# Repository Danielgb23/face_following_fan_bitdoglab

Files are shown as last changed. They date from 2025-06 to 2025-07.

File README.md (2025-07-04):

# Ventilador Seguidor de Rostos - BitDogLab

##  Descrição
Sistema inteligente de embarcados que move um ventilador para seguir rostos detectados por uma IA de visão computacional. 

[Link](https://youtu.be/tgpLVKnkNZ8) do vídeo de demonstração. 



### Proposta de projeto
Neste projeto nós propomos criar um sistema que controla a direção que uma ventoinha aponta baseado na posição da face do usuário em relação a uma câmera fixa. A câmera escolhida (ESP32) captura a imagem e envia para um notebook próximo. O notebook realiza uma análise da imagem recebida, identificando uma face ( se houver ) e as coordenadas dela em relação ao centro da câmera, depois envia essas coordenadas para o BitDogLab.
O BitDogLab, tendo a posição da face recebida, controla dois servos motores, um que controla o movimento vertical e outro o horizontal, e direciona a ventoinha para apontar para a face do usuário. Na ausência de pessoas a placa bitdog desliga automaticamente o ventilador.

### Objetivos
O principal objetivo deste projeto é desenvolver um sistema autônomo de ventilação inteligente
que responda à presença e à posição de uma pessoa em tempo real. Especificamente,
buscamos:
- Aplicar conhecimentos de sistemas embarcados e visão computacional para integrar
hardware e software de forma eficiente.
- Utilizar técnicas de reconhecimento facial para detectar a presença de usuários e sua
posição.
- Controlar dinamicamente a direção e o funcionamento de um ventilador com
servomotores, melhorando o conforto térmico.
- Otimizar o consumo de energia por meio do desligamento automático do sistema na
ausência de pessoas.

### Composição

- **ESP32-CAM**: Módulo em arduino com camera e wifi que captura imagens e envia para o backend
- **Backend em Python**: Processa imagens com OpenCV e mediapipe para detecção facial e informa os IPs com um mock de servidor DNS
- **Placa BitDogLab**: Placa de raspberry pico com upython que controla servomotores e ventilador
- **Comunicação WiFi**: Todos os componentes se comunicam sem fio

##  Componentes do Hardware

### Lista de Materiais
| Componente | Quantidade | Observações |
|---|---|---|
| Placa BitDogLab | 1 | Controlador principal |
| Módulo ESP32-CAM | 1 | Câmera |
| Servomotores | 2 | Para movimento pan-tilt |
| Ponte H L293 | 1 | Para Controlar o ventilador |
| Ventilador DC | 1 | 5V ou 12V conforme modelo |
| Fonte de alimentação 5V | 1 | Adequada para todos componentes |
|Pan Tilt| 1 | Suporte físico para o ventilador controlado pelos servos|

### Conexões Elétricas BitDogLab
1. GPIO4 PWM ventilador na ponte H
2. GPIO8 Servo horizontal
3. GPIO9 Servo vertical

### Conexões Elétricas L293 (pinos)



- 4,5,12 or 13: terra
- 16: VCC1 fonte de alimentação das portas lógicas internas (5V)
- 8: Vcc2 fonte de alimentação do ventilador
- 9: EN enable dos módulos 4 e 3 (se for nível lógico baixo deixa a saída em alta impedância)
- 15: A do módulo 4 (pulso PWM de controle em GPIO4)
- 14: saída conectada na alimentação do ventilador

### Conexões Elétricas Servo
Tower pro micro Servo 9g SG90 pinout
Configuração dos pinos
|Pin Number| 	Cor| 	Descrição|
|---|---|---|
|1| 	Marrom| 	Terra (GND)|
|2| 	Vermelho |	Alimentação 5V (VCC)|
|3| 	Laranja| 	Sinal de controle (PWM)|

### Pan tilt
O modelo de pan tilt utilizado foi impresso com uma impressora 3D usando o seguinte [modelo](https://www.thingiverse.com/thing:6008663) com [intruções de montagem](https://www.instructables.com/Pan-and-Tilt-Camera-With-ESP32-CAM-L0Cost-Robot-Co/). Os arquivos da impressora 3D também estão na pasta pantilt3d.



### Placa
Arquivos da placa PCB no diretorio placa.

##  Instalação do Software

### Firmware para ESP32-CAM
1. Instalar Arduino IDE com suporte ao ESP32-CAM ([ver guia](https://randomnerdtutorials.com/program-upload-code-esp32-cam/
))
2. Instalar o firmware no módulo com programador ou conversor USB serial.

### Backend em Python
```bash
pip install opencv-python numpy mediapipe 
```
### Firmware bitdoglab
Seguir o guia de instalação no [site](https://bitdoglab.webcontent.website/).

##  Configuração

### Arquivo esp32-cam/arduino_esp32/arduino_esp32.ino (ESP32-CAM)
```arduino
// Configurações de rede
const char* ssid = "SUA_REDE_WIFI";
const char* password = "SENHA_WIFI";

```
### Arquivo bitdog/main.py (bitdoglab)
```python
# Setup Wi-Fi (line 129)
ssid = 'SUA_REDE_WIFI'
password = 'SENHA_WIFI'
```

##  Fluxo de Operação
1. ESP32-CAM captura imagem → Envia para backend via UDP
2. Backend detecta rostos → Calcula posição central
3. Envia coordenadas → BitDogLab via WiFi
4. BitDogLab move servos → Mantém ventilador apontado para rosto

##  Como Usar
1. Energizar todos os componentes (não usar a placa bitdoglab para energizar os servos e ponte H, usar fonte de 5V externa)
2. Iniciar servidor mock dns:
   ```bash
   python backend/mock_dns_server.py
   ```
3. Iniciar backend:
     ```bash
   python backend/backend.py
   ```
3. ESP32 conecta automaticamente e inicia streaming
4. Ligar ou resetar BitDogLab se ligada para registrar no script servidor mock dns 

##  Estrutura do Projeto (há alguns arquivos auxiliares da placa e pantilt)
```
├── esp32-cam/
│   └── arduino_esp32/     #
│        └── arduino_esp32.ino   # Camera com streaming wifi          
├── backend/                # Processamento de imagem
│   ├── backend.py              # Servidor com deteção facial opencv
│   └── mock_dns_server.py   # Permite que os componentes tenham IP dinâmicos
└── bitdog/
    └── main.py   # codigo em upython para controlar os servos e o ventilador com as coordenadas do backend
```

##  Observações Importantes
1. O projeto requer boa iluminação para detecção facial adequada
2. Velocidade do ventilador pode ser ajustada no código
3. Distância ideal de operação: alguns centimetros da camera
4. Consumo elétrico total deve ser calculado para seleção da fonte

### Resultados
Após a implementação do sistema proposto e da montagem da parte mecânica foi possível validar a funcionalidade. 

A câmera ESP32 foi capaz de capturar imagens em tempo real e transmiti-las com sucesso para o notebook via Wi-Fi. O notebook processou as imagens utilizando um algoritmo de inteligência artificial de detecção facial, proveniente da biblioteca mediapipe, identificando a posição da face do usuário no campo de visão da câmera. Na iteração anterior do projeto, o detector do open CV se demonstrou insuficiente. Os testes demonstraram que, uma vez detectada a face, o sistema foi capaz de calcular corretamente a posição relativa da mesma em relação ao centro da imagem. 

Essas coordenadas foram então enviadas via wifi também ao BitDogLab, que realizou o controle dos dois servomotores conectados ao sistema e montados no pan tilt que suporta o ventilador.
Durante os testes práticos, após a montagem da parte mecânica, observou-se que os servomotores responderam da forma esperada conforme a posição da face, movendo um servo para movimentos verticais e outro para horizontais. Com ajustes no tratamento do valor de posição relativa recebido pelo bitdoglab foi possível ajustar os servos para que seguissem a posição do rosto corretamente como pode se constatar no [vídeo](https://youtu.be/tgpLVKnkNZ8).

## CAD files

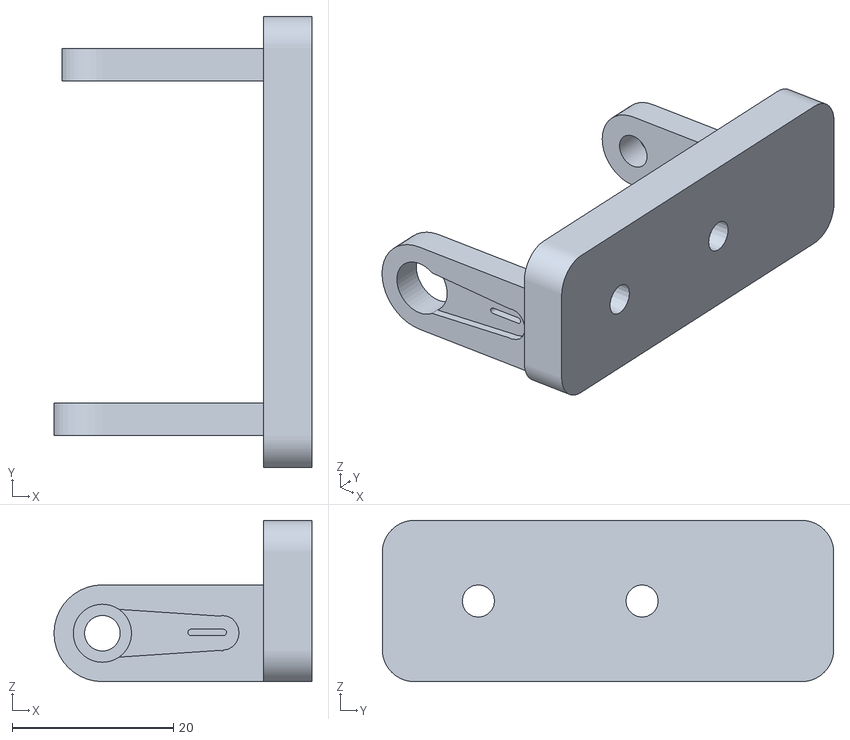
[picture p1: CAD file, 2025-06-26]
pantilt3d/SG90_MG90_Pan_and_Tilt_2a.stl
32.0 x 56.0 x 20.0

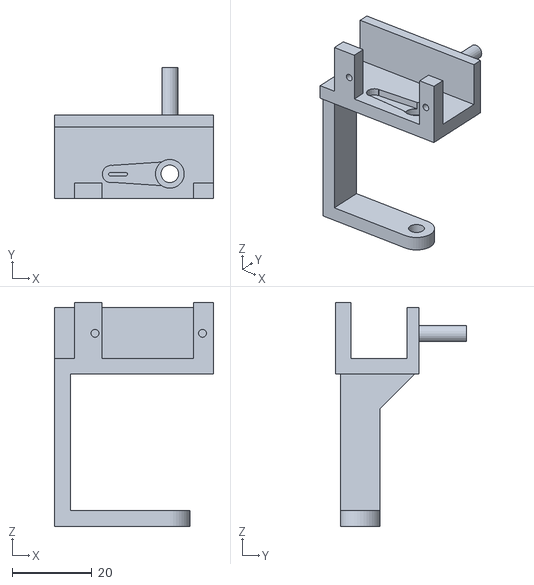
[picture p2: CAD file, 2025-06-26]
pantilt3d/Shiny_Trug_2.stl
40.0 x 33.0 x 56.2

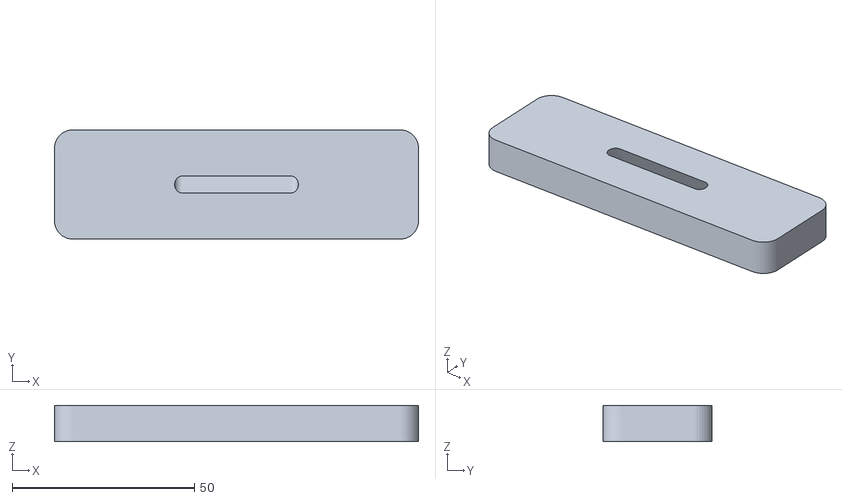
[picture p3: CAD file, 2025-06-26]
pantilt3d/Fan_base.stl
100.0 x 30.0 x 10.0

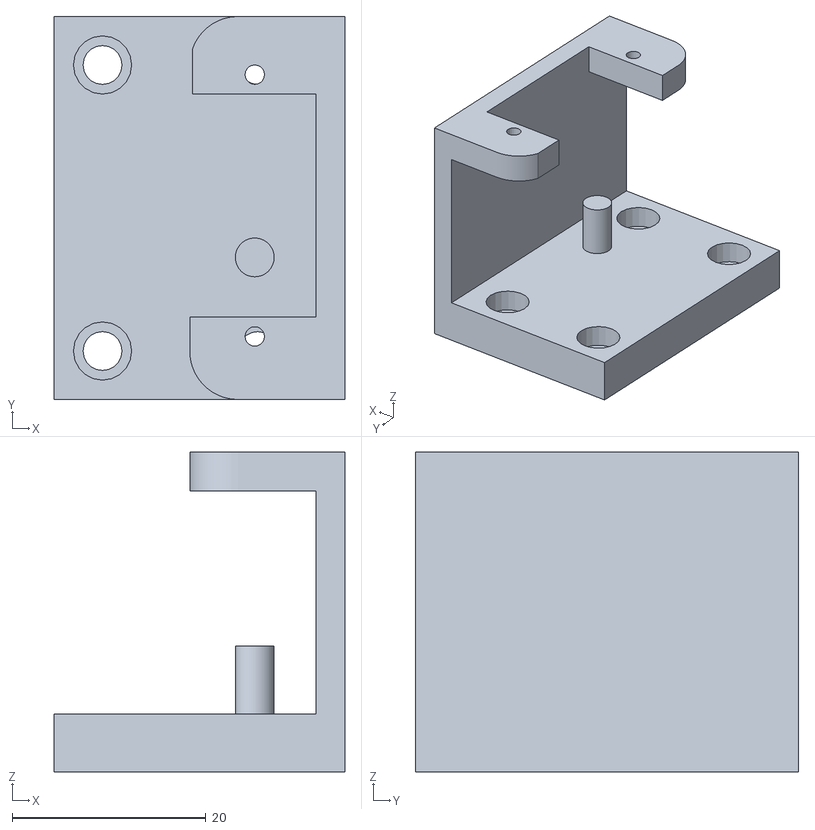
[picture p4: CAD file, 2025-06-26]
pantilt3d/Shiny_Trug_1.stl
30.0 x 39.5 x 33.0

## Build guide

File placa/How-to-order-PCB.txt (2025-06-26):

How to Order PCB

Please refer to:
https://prodocs.easyeda.com/en/pcb/order-order-pcb/index.html

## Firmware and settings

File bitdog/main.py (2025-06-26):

"""
This section controls the servo motors based on two inputs dx and dy
that represent the distance from the center of the image in the camera
using the interface function "servo_update" 

Board GPIO for project
GPIO8 for horizontal PWM
GPIO9 for vertical PWM

0° is when the fan is pointing to the center

Tower pro micro Servo 9g SG90 pinout
Pin Configuration and Descriptions
Pin Number 	Color 	Description
1 	Brown 	Ground (GND)
2 	Red 	Power Supply (VCC)
3 	Orange 	Control Signal (PWM)
"""
from machine import Pin, PWM
#Constants

#image specs
IMG_WIDTH=100
IMG_HEIGHT=100

# module of max angle (negative in other direction)
X_MAX_ANGLE=90
Y_MAX_ANGLE=90

# Setup PWM for servos (adjust pins as needed)
servo_h = PWM(Pin(8)) # GPIO8 for horizontal 
servo_v = PWM(Pin(9)) # GPIO9 for vertical

# Set frequency to 50Hz for servos
servo_h.freq(50)
servo_v.freq(50)

# Helper: Map angle (-90–90) to duty_u16 for 0.5ms–2.5ms pulse width at 50Hz
def angle_to_duty(angle):
    # Duty cycle range for -90° to 90° is approx. 1638 (0.5ms) to 8192 (2.5ms)
    return int(1638 + ((angle+90) / 180.0) * (8192 - 1638))

# Map dx, dy (image coordinates) to angles (-90°–90°)
def position_to_angle(dx, dy):
    angle_x = int(2*(dx / IMG_WIDTH) * X_MAX_ANGLE)
    angle_y = int(2*(dy / IMG_HEIGHT) * Y_MAX_ANGLE)
    return angle_x, angle_y

# interface function for the servo motors
def servo_update(dx, dy):
    angle_x, angle_y = position_to_angle(dx, dy)

    # Send angles to servos
    servo_h.duty_u16(angle_to_duty(angle_x))
    servo_v.duty_u16(angle_to_duty(angle_y))

"""
This section controls the L293 H bridge that controls the fan's power.
The interface is the function "update_fan"

hbridge L293 IC datasheet:
https://www.ti.com/lit/ds/symlink/l293.pdf

Module used: 4
Used pinout:
4,5,12 or 13: GND
16: VCC1 logic gates power source (5V)
8: Vcc2 fan power supply input
9: EN modules 4 and 3 (if L makes output high impedance)
15: A module 4 (control pulse from GPIO4)
14: output module 4 to connect on device
"""
from machine import Pin, PWM

# Set up PWM on GPIO4 at 25 kHz
fan_pwm = PWM(Pin(4))
fan_pwm.freq(50)

# Function to set fan speed (0–100%)
def update_fan(percent):
    percent = max(0, min(100, percent))  # clamp
    duty = int((percent / 100) * 65535)
    fan_pwm.duty_u16(duty)

"""
Main section

It polls waiting for udp packets at port 12345
and updates the servos with the new position
if no packages are received a timer turns off
the fan.
"""
import socket
import network
import struct

from machine import Timer

import utime

def send_udp_broadcast(message):
    # send a broadcast with the message
    sock = socket.socket(socket.AF_INET, socket.SOCK_DGRAM)  # UDP
    sock.setsockopt(socket.SOL_SOCKET, socket.SO_BROADCAST, 1)
    sock.sendto(message, ("255.255.255.255", 12347))
    sock.settimeout(3)  # Optional: avoid blocking forever
    
    #send ACK and return value or return none
    try:
        response, _ = sock.recvfrom(1024)
        sock.close()
        print("registered IP")
        return response.decode()
    except OSError:
        sock.close()
        return None


#from servos import servo_update
#from hbridge import update_fan

# timer that turns off the pwm of the fan each 15s
fan_timer=Timer()
def fan_timeout(timer):
    update_fan(0)
    print("fan timeout")
    # period=[ms]
    fan_timer.init(mode=Timer.ONE_SHOT, period=15000, callback=fan_timeout)

# Setup Wi-Fi
ssid = 'DLEA801'
password = 'fanrobot'


network.hostname("bitdog")



sta = network.WLAN(network.STA_IF)
sta.active(True)
sta.connect(ssid, password)

while not sta.isconnected():
    utime.sleep(0.5)

print('Connected to Wi-Fi:', sta.ifconfig())

# Wait until ipaddress is registered on mock dns server
resp=None
while( resp is None):
    resp=send_udp_broadcast(b"REGISTER bitdog")

# Create TCP socket server
sock = socket.socket(socket.AF_INET, socket.SOCK_DGRAM)
sock.bind(('0.0.0.0', 12345))




fan_timeout(0)
try:
    while True:
        # receives two 1 byte elements from the udp connection
        data, addr = sock.recvfrom(2)
        
        # if data is received turns on the fan each 100ms cycle
        # if it's waiting at the previous code line, the timer fan_timeout
        # will make sure the fan is off after a wait period
        update_fan(100)
        
        # bb = signed 2 byte int
        dx, dy = struct.unpack('bb', data)
        print(f"dx={dx}, dy={dy}")

        # update servos position
        servo_update(dx+15,-dy*0.9-15)
        
        utime.sleep(0.1)
        
# when the program is interrupted turns off all pwm signals
except KeyboardInterrupt:
    print("User interrupt")
finally:
     servo_h.deinit()
     servo_v.deinit()
     fan_pwm.deinit()

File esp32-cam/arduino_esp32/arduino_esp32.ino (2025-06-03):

//esp32 by Espressif Systems version 3.2.0

#include "esp_camera.h"
#include <WiFi.h>
#include <WiFiUdp.h>


// WiFi config
const char* ssid = "DLEA801";
const char* password = "fanrobot";

// mock DNS UDP config
const int picPort = 12346;
const char* backend_name="backend";

//timer interrupt
esp_timer_handle_t timer;
volatile bool requestFlag = true;

WiFiUDP udp;
WiFiUDP udp_dns;

String udpAddress;
String udpAddressAux;
IPAddress apip;

// mock dns server resolve function with timeout
// This function sends a request to the backend in order to receive the IP address of the notebook
String resolve_name(const char* name) {
  const unsigned long timeout_ms = 15;
  String message = "RESOLVE " + String(name);
  //make a the request as a broadcast
  udp_dns.beginPacket("255.255.255.255", 12347);
  udp_dns.print(message);
  udp_dns.endPacket();

  //delay(20);

  //Receives the IP from the notebook
  unsigned long start = millis();
  while (millis() - start < timeout_ms) {
    int packetSize = udp_dns.parsePacket();
    if (packetSize) {
      char reply[64];
      
      int len = udp_dns.read(reply, sizeof(reply) - 1);
      reply[len] = '\0';
      return String(reply);
    }
    //delay(20);  // short delay to avoid busy loop
  }
  return "NOT_FOUND";

}

//configure the camera
void startCamera() {
  camera_config_t config;
  config.ledc_channel = LEDC_CHANNEL_0;
  config.ledc_timer = LEDC_TIMER_0;
  config.pin_d0 = 5;
  config.pin_d1 = 18;
  config.pin_d2 = 19;
  config.pin_d3 = 21;
  config.pin_d4 = 36;
  config.pin_d5 = 39;
  config.pin_d6 = 34;
  config.pin_d7 = 35;
  config.pin_xclk = 0;
  config.pin_pclk = 22;
  config.pin_vsync = 25;
  config.pin_href = 23;
  config.pin_sscb_sda = 26;
  config.pin_sscb_scl = 27;
  config.pin_pwdn = 32;
  config.pin_reset = -1;
  config.pin_xclk = 0;
  config.xclk_freq_hz = 20000000;
  config.pixel_format = PIXFORMAT_JPEG;

  //Define image parameters
  if(psramFound()){
    config.frame_size = FRAMESIZE_VGA; //640 × 480
    config.jpeg_quality = 4;
    config.fb_count = 2;
  } else {
    config.frame_size = FRAMESIZE_QQVGA;
    config.jpeg_quality = 12;
    config.fb_count = 1;
  }

  esp_err_t err = esp_camera_init(&config);
  sensor_t * s = esp_camera_sensor_get();
  s->set_brightness(s, 1);     // -2 to 2
  s->set_contrast(s, -1);       // -2 to 2
  s->set_saturation(s, 0);     // -2 to 2
  s->set_gain_ctrl(s, 1);      // Auto gain
  s->set_exposure_ctrl(s, 1);  // Auto exposure
  s->set_awb_gain(s, 1);       // Auto white balance gain

  //Error message
  if (err != ESP_OK) {
    Serial.printf("Camera init failed with error 0x%x", err);
    return;
  }
}

//timer interrupt
void  onTimer(void * arg) {
  requestFlag = true;  // Set flag on interrupt
}

void setup() {
  Serial.begin(115200);
  WiFi.begin(ssid, password);
  while (WiFi.status() != WL_CONNECTED) {
    delay(500);
    Serial.print(".");
  }
  Serial.println("WiFi connected");

  startCamera();
  udp.begin(picPort);
  udp_dns.begin(12347);

   // Create a periodic timer
  const esp_timer_create_args_t timer_args = {
      .callback = &onTimer,
      .arg = nullptr,
      .dispatch_method = ESP_TIMER_TASK,
      .name = "periodic_timer"
  };

  
  esp_timer_create(&timer_args, &timer);
  esp_timer_start_periodic(timer, 15 * 1000000);  // 10s in microseconds
  
  
  //first dns request
  udpAddress[0]='\0';
  while(!apip.fromString(udpAddress)) // waits until it has a valid ip address
      udpAddress = resolve_name(backend_name);
    
}

void loop() {
  //Make a DNS requent periodically trough timer interrupt
  if (requestFlag) {
    requestFlag = false;
    //request backend address
    udpAddressAux = resolve_name(backend_name);
    if(apip.fromString(udpAddressAux)) //tests if recovered string is an ip address
      udpAddress=udpAddressAux;
  }
  //Error message if the camera capture fails
  camera_fb_t *fb = esp_camera_fb_get();
  if (!fb) {
    Serial.println("Camera capture failed");
    return;
  }

  // Send image size first
  udp.beginPacket(udpAddress.c_str(), picPort);
  udp.write((uint8_t*)&fb->len, sizeof(fb->len));
  udp.endPacket();

  // Send image data in chunks (max 1460 bytes per UDP packet)
  const size_t maxPacketSize = 1460;
  size_t sent = 0;
  while (sent < fb->len) {
    size_t packetSize = min(maxPacketSize, fb->len - sent);
    udp.beginPacket(udpAddress.c_str(), picPort);
    udp.write(fb->buf + sent, packetSize);
    udp.endPacket();
    sent += packetSize;
    delay(1);
  }

  esp_camera_fb_return(fb);
  delay(150);  // capture every []ms


}

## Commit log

2025-05-07 servo, H bridge
2025-05-08 added backend for computer and network for the bitdog board, merged bitdog code into main.py
2025-05-09 mock dns server to not hardcode IP, ESP32CAM aruino code, image receiver
2025-05-10 merged image receiver from esp32 and position sender to bitdog into one script
2025-05-10 face detection working on esp32-cam image
2025-05-10 arduino code with interrupt timed mock dns requests so they don't overload the server
2025-06-03 more robust valid ip address test on mock dns request for arduino camera
2025-06-24 signal vertical servo inverted
    [main.py]
2025-06-26 adjustments in position of the servos
2025-06-26 pantilt 3D
    [Fan_base.stl, SG90_MG90_Pan_and_Tilt_2a.stl, Shiny_Trug_1.stl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]
